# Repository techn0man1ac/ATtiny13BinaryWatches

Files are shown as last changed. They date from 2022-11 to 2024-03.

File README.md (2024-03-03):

# ATtiny13BinaryWatches

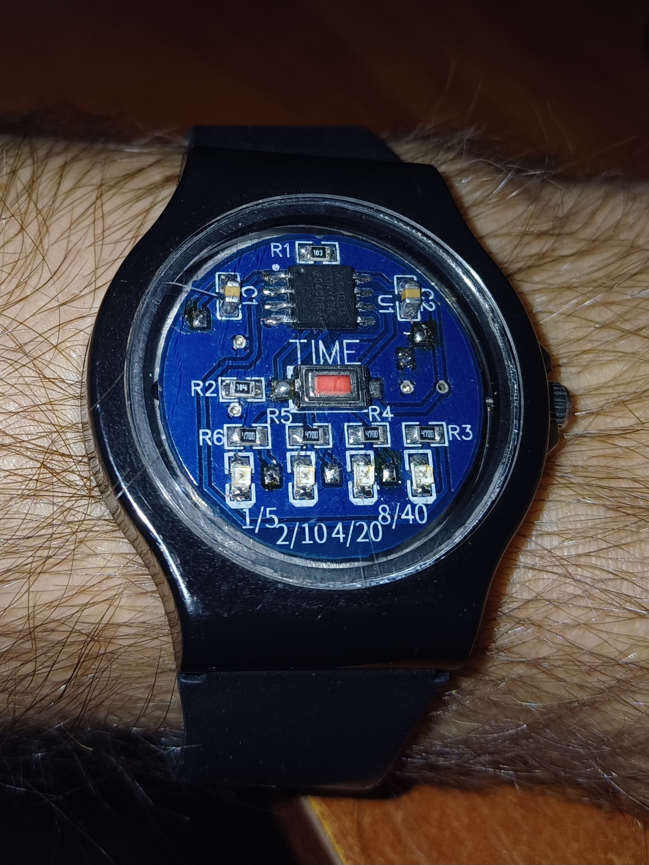
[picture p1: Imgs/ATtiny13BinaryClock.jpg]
PCB in real life


Simple Binary Watches with 4 LED(1/5, 2/10, 4/20, 8/40), it mean 5 minute accuracy indicate.

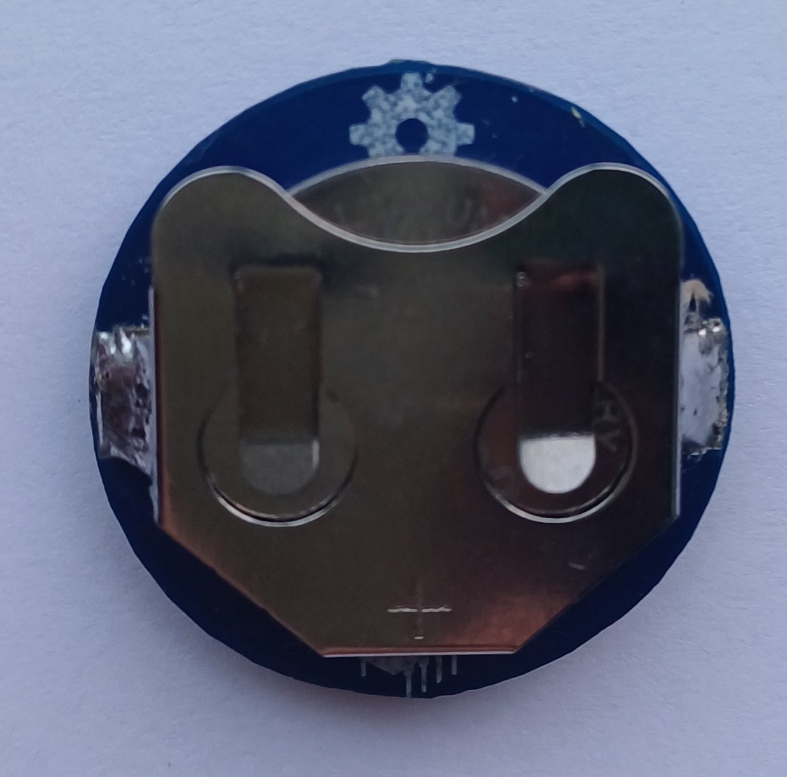
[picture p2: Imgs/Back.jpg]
PCB battery


# Video demonstration:

https://youtu.be/qP_2BFFjp1M

# How it's work?

Every 0.5 sec CPU wake up(cycle iteration time 100 nS) and increase milliseconds value and come sleep mode(3 uA). 

If you press button "TIME();" it show hours and minutes(0.5 seconds per value) in binary mode in 4 LEDs.

# 3D model PCB:

PCB Up side:

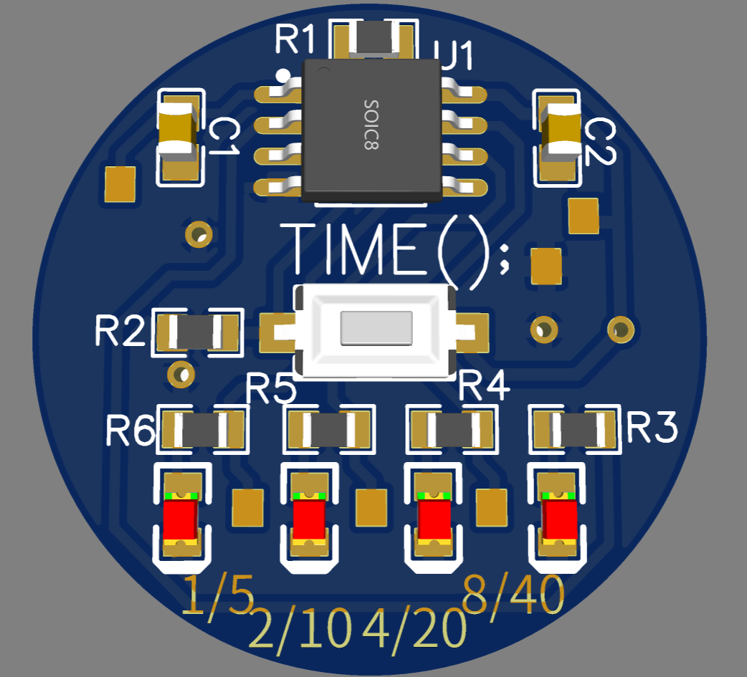
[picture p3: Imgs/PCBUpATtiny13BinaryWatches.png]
PCB Up


PCB Down side:

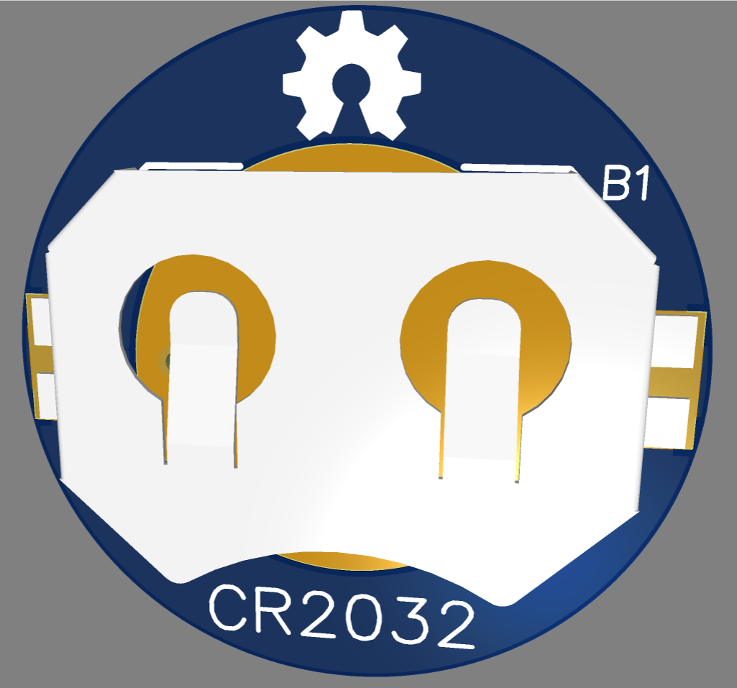
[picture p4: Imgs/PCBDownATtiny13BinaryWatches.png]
PCB Down side


PCB size 27 mm in diameter(size little biger CR2032 battery):

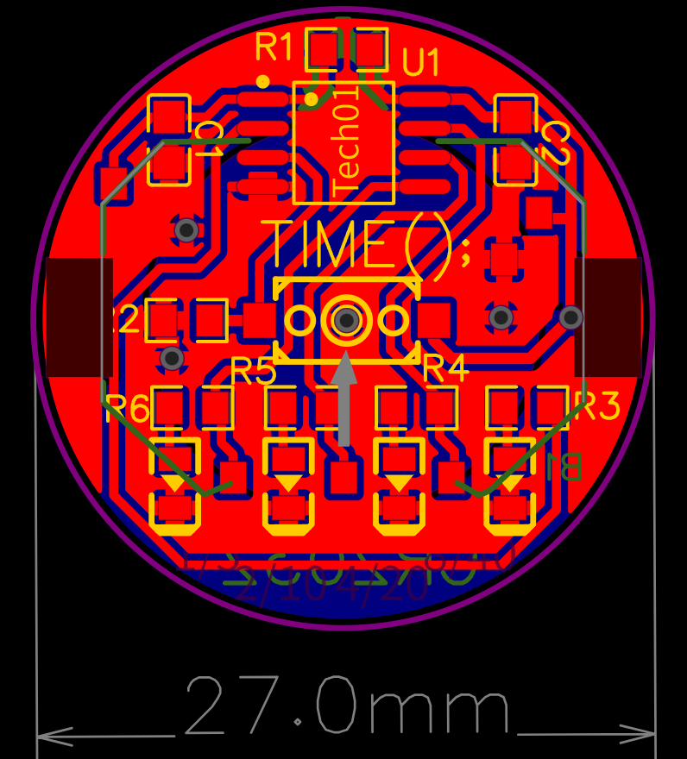
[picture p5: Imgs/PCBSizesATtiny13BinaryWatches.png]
PCB Size


The thickness of the board is recommended to take 0.8mm otherwise it may not fit into the case.

# Gerber files and 3D model:

Files for fabrication:

https://github.com/techn0man1ac/ATtiny13BinaryWatches/tree/main/PCB

# PCB home page:

Fresh board project here:

https://oshwlab.com/raznie.podelki/attiny13binarywatches

# Schematic:

It's have simple schematic, there are 15 components in total:

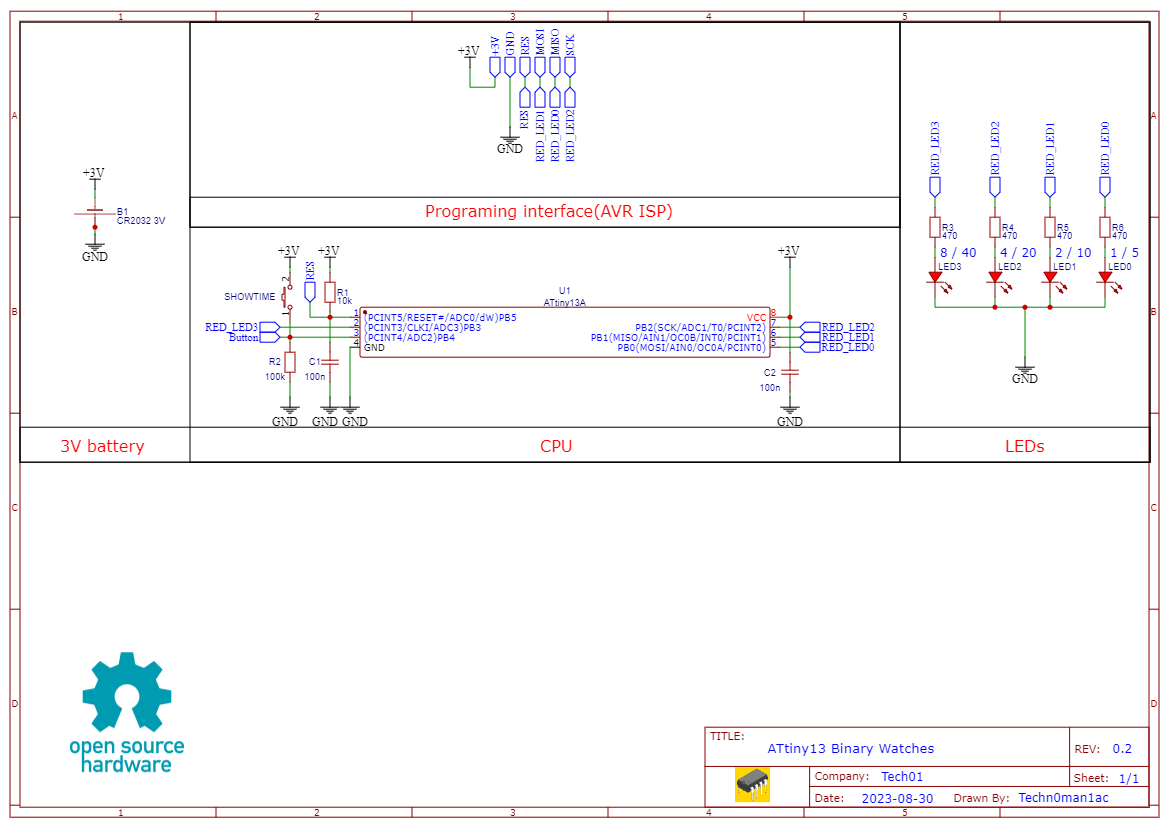
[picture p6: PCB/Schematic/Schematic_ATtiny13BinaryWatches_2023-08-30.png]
Schematic clock


# How to flash

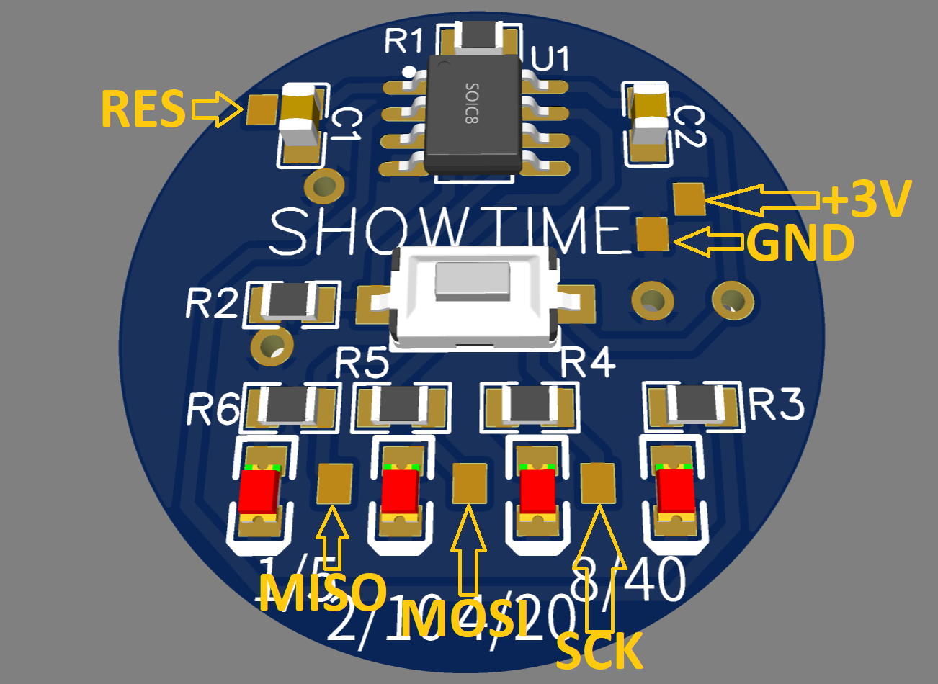
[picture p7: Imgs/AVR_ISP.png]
AVR ISP programmer pinout


Here is pinout for AVR ISP programmer - MOSI ATtiny13 -> MISO programer(Digital Pin 11), MISO->MOSI(Digital Pin 12), SCK->SCK(Digital Pin 13) RES->Reset(Digital Pin 10). How to flash ATtiny13 with Arduino:

https://www.hackster.io/taunoerik/programming-attiny13-with-arduino-uno-07beba

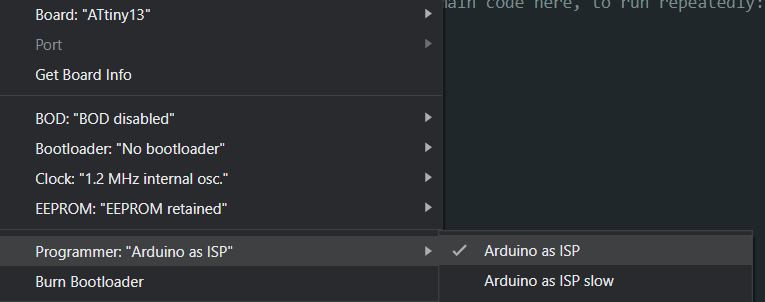
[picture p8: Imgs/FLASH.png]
FLASH


ATtiny13 core selections:

- Board: ATtiny 13

- BOD: BOD Disabled

- Clock: 1.2 MHz internal osc.

- Compiler LTO: Enable

- Port: (Your Arduino port)

- Programmer: Arduino as ISP

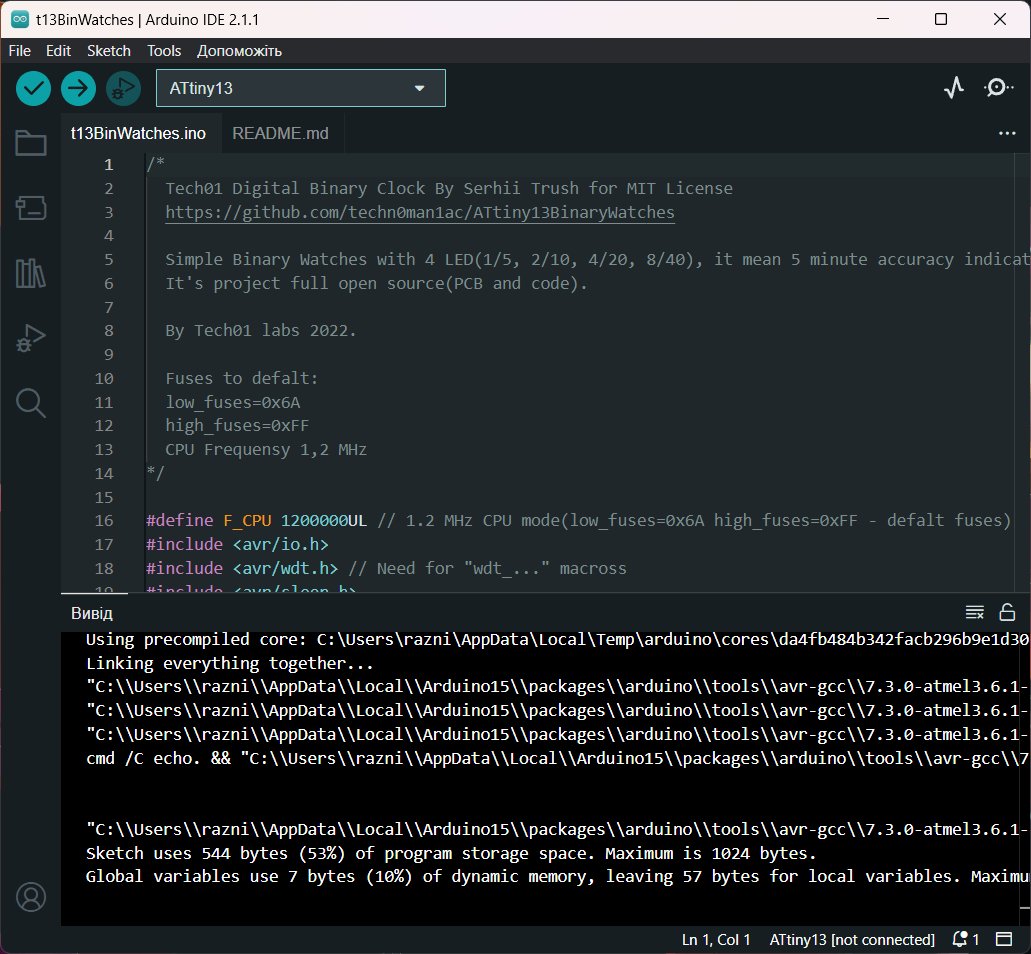
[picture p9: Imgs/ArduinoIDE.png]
Arduino IDE


Source code(for Arduino IDE - "t13B Watches.ino") here:

https://github.com/techn0man1ac/ATtiny13BinaryWatches/tree/main/t13BinWatches

It's project full open source(PCB and code).

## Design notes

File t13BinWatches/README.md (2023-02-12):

Fuses to defalt:

low_fuses=0x6A

high_fuses=0xFF

Frequency CPU is 1,2 MHz

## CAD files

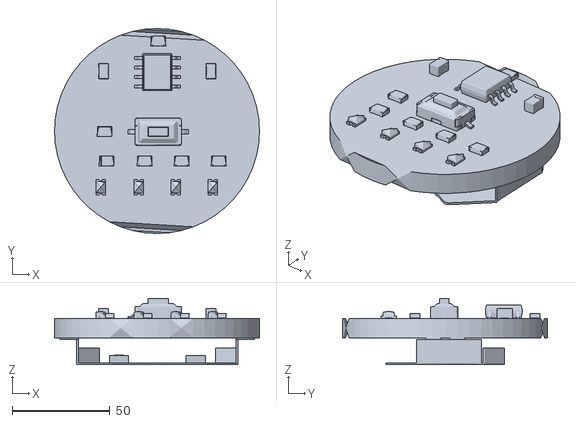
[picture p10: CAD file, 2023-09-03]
PCB/3D model/OBJ_PCB_Circle_ATtiny13BinaryWatches.obj
105.1 x 105.1 x 34.1

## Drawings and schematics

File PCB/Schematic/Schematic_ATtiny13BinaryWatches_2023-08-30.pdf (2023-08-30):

# Programing interface(AVR ISP)

3V battery | CPU | LEDs RES

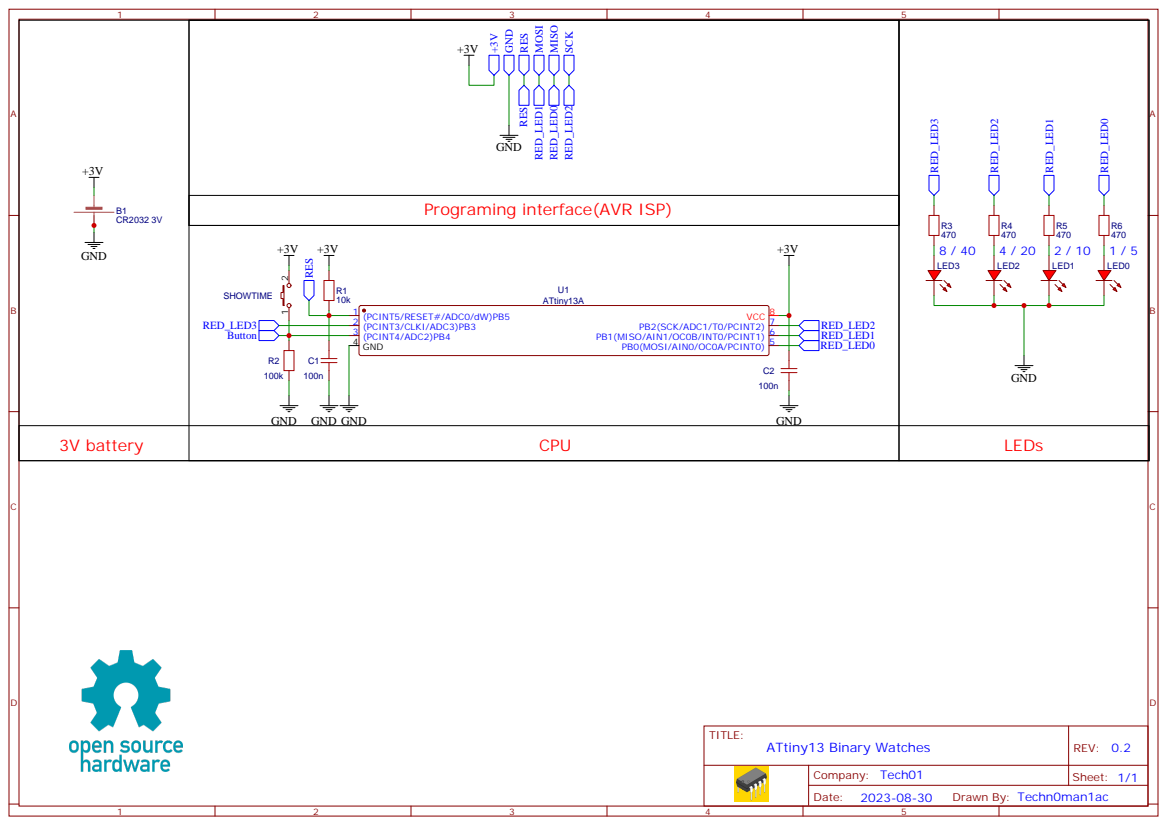
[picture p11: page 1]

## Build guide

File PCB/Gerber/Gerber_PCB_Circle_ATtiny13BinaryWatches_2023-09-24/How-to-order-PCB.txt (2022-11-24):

How to Order PCB

Please refer to:
https://docs.easyeda.com/en/PCB/Order-PCB

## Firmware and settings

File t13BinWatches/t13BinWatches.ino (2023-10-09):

/*
  Tech01 Digital Binary Clock By Serhii Trush for MIT License
  https://github.com/techn0man1ac/ATtiny13BinaryWatches

  Simple Binary Watches with 4 LED(1/5, 2/10, 4/20, 8/40), it mean 5 minute accuracy indicate.
  It's project full open source(PCB and code).

  By Tech01 labs 2022.

  Fuses to defalt:
  low_fuses=0x6A
  high_fuses=0xFF
  CPU Frequensy 1,2 MHz
*/

#define F_CPU 1200000UL  // 1.2 MHz CPU mode(low_fuses=0x6A high_fuses=0xFF - defalt fuses)
#include <avr/io.h>
#include <avr/wdt.h>  // Need for "wdt_..." macross
#include <avr/sleep.h>
#include <avr/power.h>
#include <avr/interrupt.h>

#define msPerCycleReal 559    // it's mean 500 ms in real life
#define MsIn12Hours 43200000  // 43200000 ms -> 43200 sec = 12h

uint8_t Hours = 9;    // <- Set time in hours here(0..11)
uint8_t Minutes = 15;  // <- Set time in minutes here(5..55)

volatile uint32_t MSec = Hours * 3600000 + Minutes * 60000;  // 33300000 is 09:15

uint8_t Mode = 0;

ISR(WDT_vect) {            // If button ont press code iteration time is 100 nS
  MSec += msPerCycleReal;  // 500 ms per cycle

  if (MSec >= MsIn12Hours) {
    MSec = MSec - MsIn12Hours;  // increment MSec value compensation -> 43199999 + 555 = 43200554 -> 554
  }

  if (PINB & (1 << PINB4) || Mode > 0) {  // if (digitalRead(4) == HIGH) or we in show time mode
    Mode = Time(Mode);                    // Show time on LED in binary format
  }

  WDTCR |= (1 << WDTIE);
}

int main() {
  ADCSRA &= ~(1 << ADEN);  //Disable ADC
  ACSR = (1 << ACD);       //Disable the analog comparator
  // Set up Port B as Input
  DDRB = 0b01111;  // Use 470 ohm resistor per LED
  wdt_reset();
  wdt_enable(WDTO_500MS);  // Set watchdog timer to trigger every 500 ms
  WDTCR |= (1 << WDTIE);   // Set watchdog timer in interrupt mode
  sei();                   // Enable global interrupts

  set_sleep_mode(SLEEP_MODE_PWR_DOWN);
  while (1) {
    sleep_enable();
    sleep_cpu();
  }
  return 0;
}

uint8_t Time(uint8_t currState) {
  uint8_t LEDValue = 0;
  switch (currState) {  //Final state machine
    case 0:
      if (!MSec) {  // protect divide by zero(if MSec not = 0), thanks ChatGPT
        Hours = 0;
      } else {
        Hours = MSec / 3600000;  // 3600 sec per hour * 1000(ms)
      }

      if (Hours == 0) {
        LEDValue = 12;  //
      } else {
        LEDValue = Hours;
      }
      DDRB = 0b1111;  // Turn on ouptuts

      currState = 1;  // Next state
      break;

    case 1:
      if (!MSec) {  // protect divide by zero, thanks ChatGPT
        Minutes = 0;
      } else {
        Minutes = ((MSec / 60000) % 60) / 5;  // 60 Seconds per minutes(5 min to discrete)
      }

      LEDValue = Minutes;

      currState = 2;
      break;

    case 2:
      LEDValue = 0;
      DDRB = 0b0000;  // Turn off outputs(Hi-Z state) for low consumption
      currState = 0;
      break;

    default:
      return -1;  // some wrong
  }

  PORTB = LEDValue;  // Set Port B to LEDValue
  return currState;
}

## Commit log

2022-11-18 Change№000
    Add source code
2022-11-18 Change #001
    Add schematics picture
2022-11-24 Change#003
    Add:
    0) Schematic;
    1) Gerbers;
    2) 3D model(PCB);
    3) Firmware and scource code(Arduino IDE);
    4) Project for Proteus 8.15.
    [Drill_PTH_Through.DRL, Drill_PTH_Through_Via.DRL, Gerber_BoardOutlineLayer.GKO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]
2023-01-16 Change#005
    Add correct value to variable "msPerCycleReal"
    [t13BinWatches.ino]
2023-02-12 Change#003
    New PCB
    [Drill_PTH_Through.DRL, Drill_PTH_Through_Via.DRL, Gerber_BoardOutlineLayer.GKO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]
2023-02-12 Change #004
    Fuses to defalt:
    low_fuses=0x6A
    high_fuses=0xFF
    Frequency CPU is 1,2 MHz
2023-08-30 Change#005
    Off internal resistors
2023-08-30 Change#006
    Add real photos device
2023-08-30 Change#007
    Add PCB photos
2023-08-30 Change#008
    Add resistors for LEDs
2023-08-30 Change#008
    Add resistors for LED
2023-08-30 Change#009
    PCB v0.2
2023-08-30 Change#009
    Add schematics blocks and programing interface
2023-08-30 Change #010
    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
2023-08-30 Change#011
    Add new 3D model with resistors for LED
2023-08-30 Change#014
    Add new PCB gerbers
    [Drill_PTH_Through.DRL, Drill_PTH_Through_Via.DRL, Gerber_BoardOutlineLayer.GKO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]
2023-08-30 Change#016
    Add ArduinoIDE screenshot
2023-08-30 Change#017
    Add Arduino IDE screenshot
2023-09-03 Change#017
    Some cosmetic changes
    [Drill_PTH_Through.DRL, Drill_PTH_Through_Via.DRL, Gerber_BoardOutlineLayer.GKO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]
2023-09-03 Change#018
    Add some cosmetic changes
    [OBJ_PCB_Circle_ATtiny13BinaryWatches.obj]
2023-09-24 Change №021
    Add new gerber files
    [Drill_PTH_Through.DRL, Drill_PTH_Through_Via.DRL, Gerber_BoardOutlineLayer.GKO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]
2023-10-02 Change#021
    Remove global variable "ButtonPress" and add some port modes for low consumption
2023-10-02 Change#022
    Add photo clock in case
2023-10-05 Change#023
    Add Hi-Z mode to ports, for lower power consumption
2023-10-05 Change#023
    Change some device datas
